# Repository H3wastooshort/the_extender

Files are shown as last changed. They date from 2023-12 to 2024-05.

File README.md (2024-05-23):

# The Extender
Modern phones suck in theor own unique way, don't they?
Hard-to-replace or -expand lithium cells, no expandable storage, and worst of all: no headphone jack!

This projects aims to fix some of those flaws by
combining a powerbank, USB hub, USB audio, and RP2040 IC into one very cursed PCB.

top pcb view
bottom pcb view
rotating pcb GIF
schematic

## Working Principle
5V power and battery charging is handled by an IP5310 powerbank IC.

The PCB connects to a phone via a low-profile 90° USB Type C cable (either [DIY](/cable) or [bought](https://de.aliexpress.com/item/1005005371248824.html)).
Once connected, the RP2040 turns on 5V power, then uses the FUSB302 to tell the phone via USB Power Delivery,
that it should keep charging while also switching into USB Data Host mode.

The phone then connects to the CH334F USB Hub IC, which in turn connects to several things:
 * a USB 3.0 socket for a USB Stick which is used to expand the internal storage,
 * the HS-100B USB audio IC, (only powered on when headphones are connected)
 * the RP2040 for HID volume and playback control aswell as FW Updates,
 * and an external USB 2.0 socket for whatever you desire.

a diagram showing data flow in the extender

## 3D-printable case
WIP

## schematic POIs

### HS-100B Audio IC
 * The Audio IC circuit is based on a low-resolution image of a reference design i found online.
 * 5V Power to the IC gets cut va a MOSFET when the headphones are disconnected. An RC circuit prevents loose plugs from causing issues. (Turns off about 1 second after unplugging)
 * The datasheet is quite sparse
 * The EEPROM data lines are connected to the RP2040, so that it can emulate the EEPROM in the future. This is not requred.

### IP5310 power-bank IC
 * I2C variant is unobtainium
 * MOSFET between VOUT and rest of system, so that power to phone and other components can be controlled
   even though VOUT can't.
 * if needed, a solder jumper can be cut and shottky diode put in place to prevent current flowing back into the IC
 * KEY pin connected to RP2040. might be needed, i don't know, should turn on when detecting a load
 * D+ and D- not connected because there is very little space. the CC lines should suffice

### CH334F
 * clock line can be grounded to use internal OSC, but this is discouraged in its datasheet.
   RP2040 is to provide a better clock once programmed.
 * 

### RP2040
 * main purpose is to communicate via USB C PD
 * might supply clock for hub
 * might be used to emulate EEPROMs for USB Hub and Audio

## more info

The [idea](/idea) directory has some partially outdated notes.

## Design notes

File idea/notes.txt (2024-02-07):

IP5XXX I2C Driver: https://git.kernel.org/pub/scm/linux/kernel/git/torvalds/linux.git/plain/drivers/power/supply/ip5xxx_power.c
IP5306 Library: https://github.com/bheesma-10/IP5306_I2C
USB C PD Stuff: https://github.com/CRImier/AltmodeFriend/tree/main ; https://github.com/CRImier/MyKiCad/tree/master/Peripherals/altmode_friend
Simple FUSB302 Lib: https://github.com/stacksmashing/tamarin-c/blob/main/FUSB302.h

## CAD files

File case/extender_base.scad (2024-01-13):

/*battery=[60,55,25];

wall_thickness=3;

module __Customizer_Limit__ () {}*/

board=[52,52,7];

translate([0,0,-(board.z+battery.z)]) union() {
difference() {
union() {
	translate([-board.x/2 -wall_thickness/2, 0,0]) cube([board.x+wall_thickness*2,board.y+wall_thickness*2,board.z+wall_thickness]);

	translate([-battery.x/2 -wall_thickness/2, 0,board.z]) 
		difference() {
			cube([battery.x+wall_thickness*2,battery.y+wall_thickness*2,battery.z+wall_thickness]);
			translate([wall_thickness,wall_thickness,wall_thickness+0.001]) cube(battery);
	}
}
union() {
	translate([-board.x/2, wall_thickness, wall_thickness]) cube([board.x,board.y-wall_thickness,board.z+wall_thickness*2]);
	translate([-board.x/2, 0, wall_thickness]) cube([board.x,wall_thickness, board.z]);
}
}


//connector fill here 
}

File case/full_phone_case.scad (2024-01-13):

phone=[80,165,10];

phone_corner_radius=15;

//distance from bottom to naerest of naerest button on the right
button_cutout_right_start=12;
//distance from bottom to farthest edge of farthest button on the right
button_cutout_right_stop=15;
//distance from bottom to farthest edge of farthest button on the left
button_cutout_left_start=0;
//distance from bottom to farthest edge of farthest button on the left
button_cutout_left_stop=0;

battery=[60,55,25];

wall_thickness=3;

module __Customizer_Limit__ () {}

include <extender_base.scad>


//phe case stoff here

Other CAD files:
case/stitch_on_case.scad

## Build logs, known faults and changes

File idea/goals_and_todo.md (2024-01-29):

#### Legend
[F] Failed / not implementing
[ ] Not yet finished
[-] In Progress
[X] Done

## Goals:
### Main
[-] USB PD Power SRC and Data Device (not Host)
[X] Expand Storage
[X] Connect Headphones
	[X] Only enable headphones if present
	[X] Only enable microphone if present
[X] Charge via USB C
[-] Low Profile USB C Cable
### Additional
[F] Charge other devices via USB C
[X] Have extra USB data socket
[-] Volume Controls on headphone Cable
	[X] HW
	[ ] SW

## TODO
### Main
 * CHECK SWREG DESIGN! (Inductor values, layout, ...)
 * COMPARE DIY FOOTPRINTS WITH LCSC VERSIONS!
 * reconsider DIY cable design. make version w/o USB3
 * battery protection PCB?
 * make combined stencil

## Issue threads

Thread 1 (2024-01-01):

Altmode Friend board

CRImier, 2024-01-01:
Figure out a way to get me [your address[(https://gist.github.com/CRImier/2b8e9f327e148f9c27f29578b8ef220a), I can mail you an Altmode Friend devboard!

H3wastooshort, 2024-01-01:
Thank you very much!

You can message me on Matrix at [@h3:tchncs.de](https://matrix.to/#/@h3:tchncs.de) if that's is alright for you.

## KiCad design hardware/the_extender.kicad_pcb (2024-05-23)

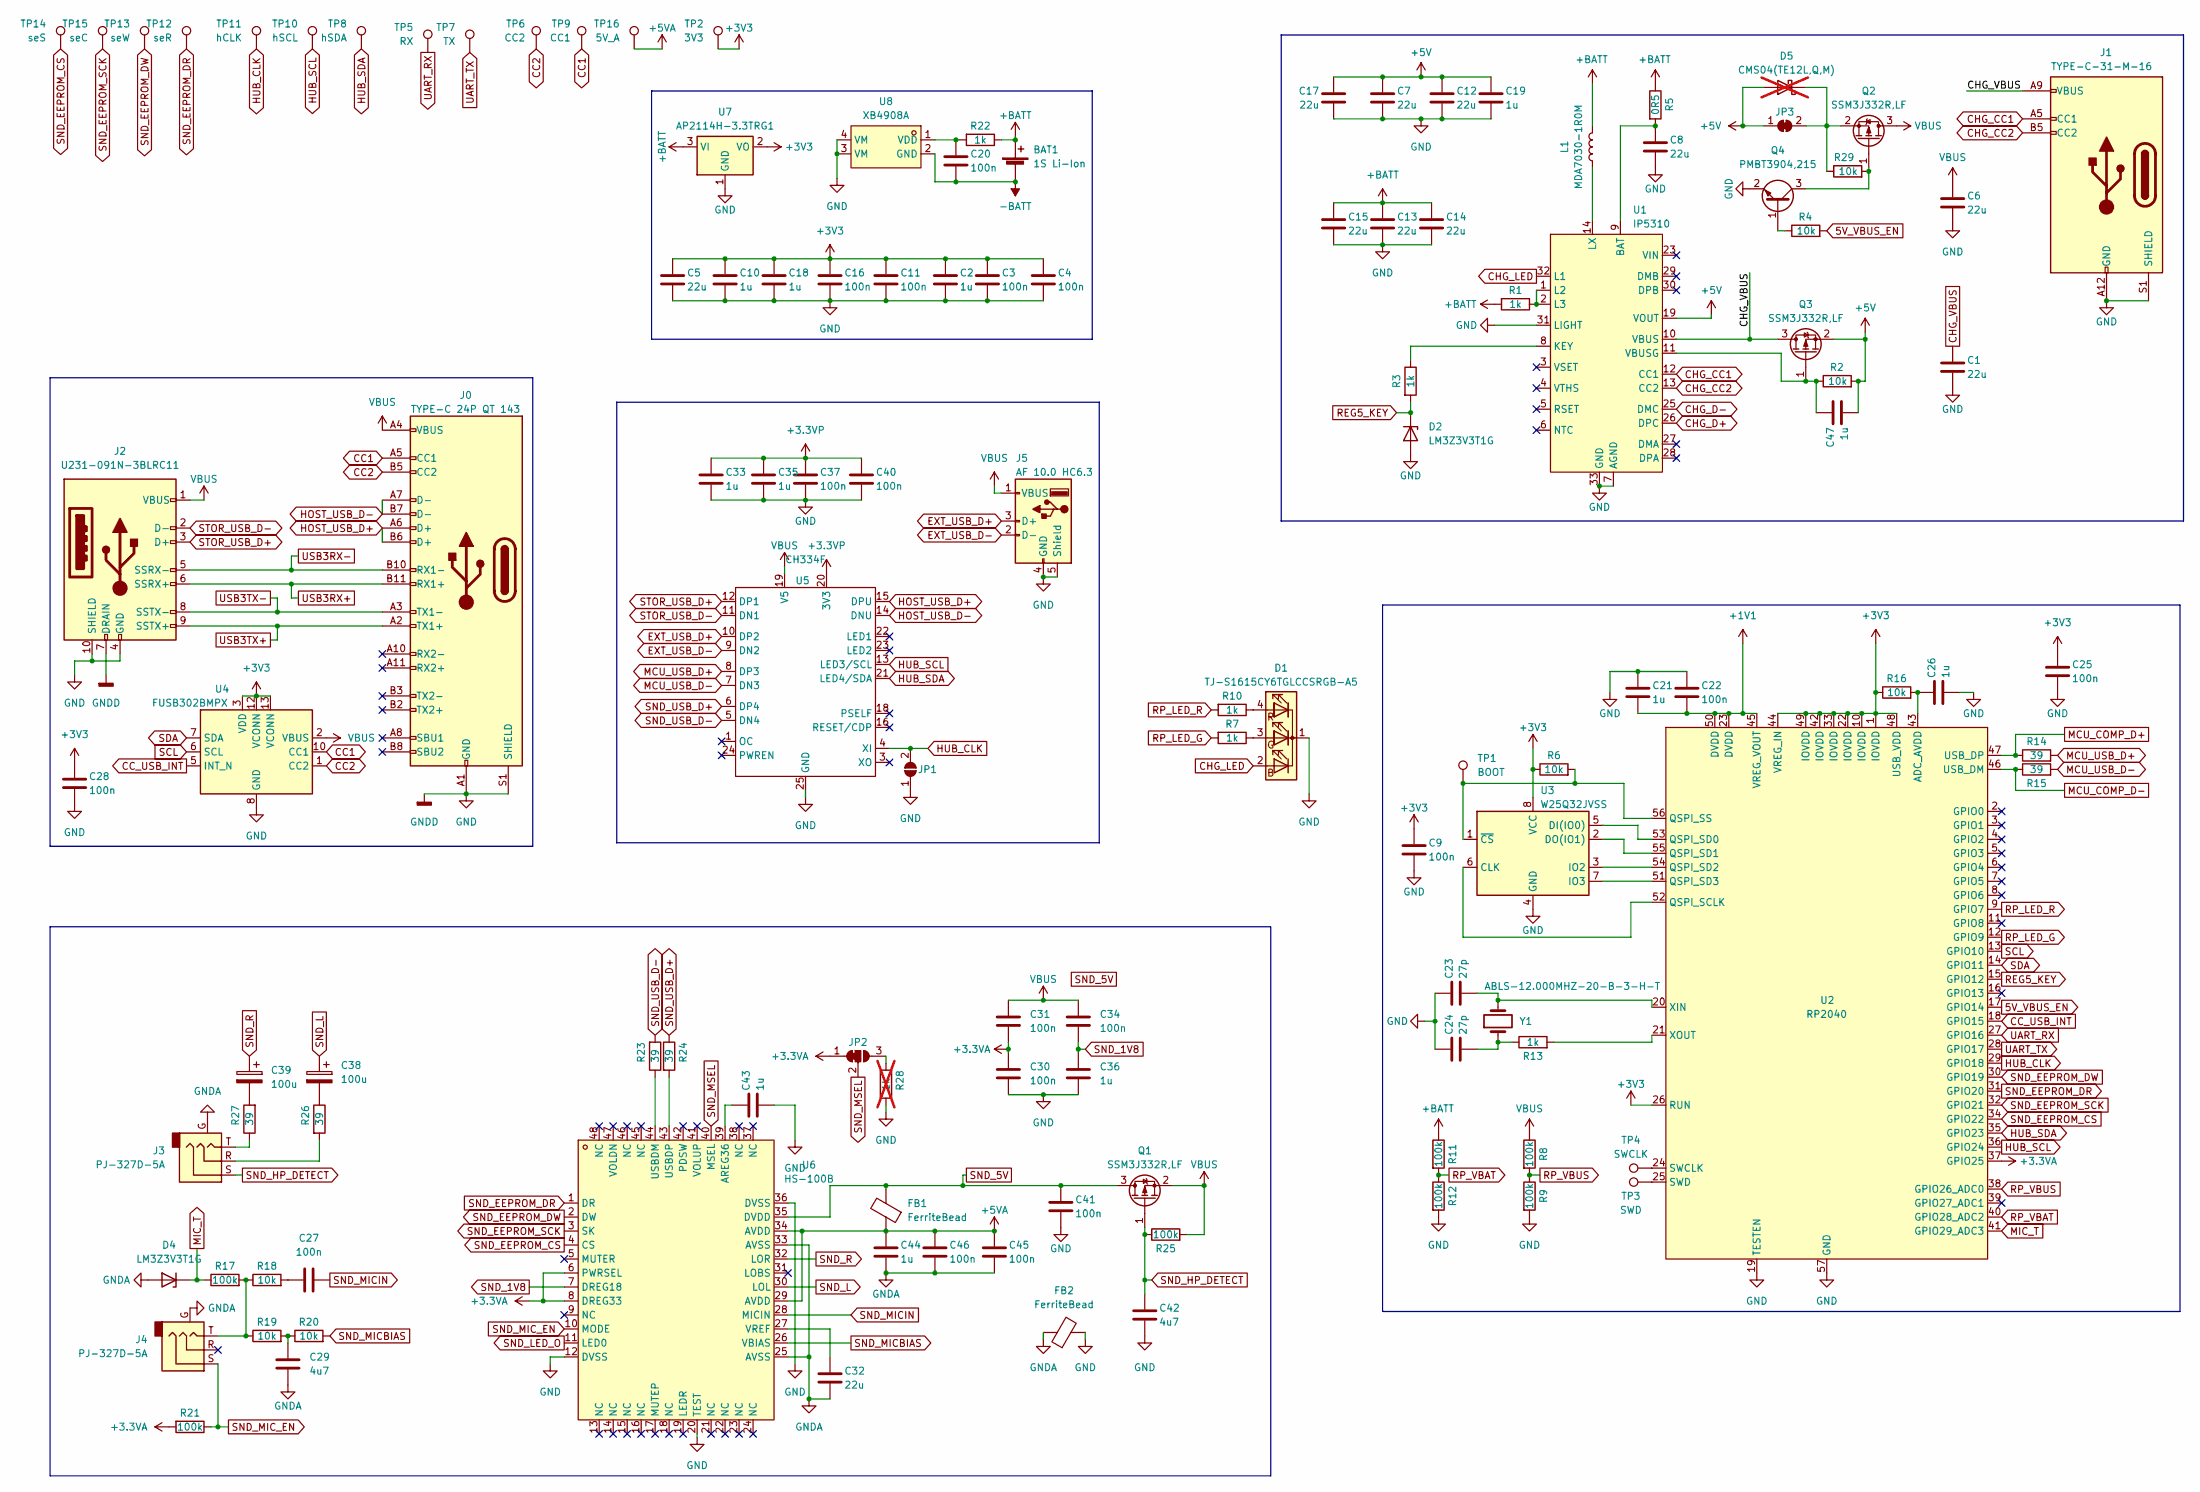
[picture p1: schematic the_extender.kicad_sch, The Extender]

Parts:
BAT1: 1S Li-Ion; PinHeader_1x02_P2.54mm_Vertical
C1, C5, C6, C7, C8, C12, C13, C14, C15, C17, C32: 22u; C_1206_3216Metric_Pad1.33x1.80mm_HandSolder; LCSC C12891
C2, C10, C18, C19, C21, C26, C33, C35, C36, C43, C44, C47: 1u; C_0805_2012Metric_Pad1.18x1.45mm_HandSolder; LCSC C116352
C3, C4, C9, C11, C16, C20, C22, C25, C27, C28, C30, C31, C34, C37, C40, C41, C45, C46: 100n; C_0805_2012Metric_Pad1.18x1.45mm_HandSolder; LCSC C1711
C23, C24: 27p; C_0805_2012Metric_Pad1.18x1.45mm_HandSolder; LCSC C525289
C29, C42: 4u7; C_0805_2012Metric_Pad1.18x1.45mm_HandSolder; LCSC C1779
C38, C39: 100u; C_1206_3216Metric_Pad1.33x1.80mm_HandSolder; LCSC C15008
D1: TJ-S1615CY6TGLCCSRGB-A5; LED-ARRAY-SMD_4P-L1.6-W1.5-BL-FD; LCSC C601684
D2, D4: LM3Z3V3T1G; D_SOD-323_HandSoldering; LCSC C46279
D5: CMS04(TE12L,Q,M); D_SOD-128; LCSC C603062; not fitted
FB1, FB2: FerriteBead; L_0805_2012Metric_Pad1.05x1.20mm_HandSolder; LCSC C394433
J0: TYPE-C 24P QT 143; TYPE-C-SMD_C9900025773; LCSC Part C5156605
J1: TYPE-C-31-M-16; LCSC C283541
J2: U231-091N-3BLRC11; USB-A-TH_XKB_U231-091N-XXX; LCSC Part C2880594
J3, J4: PJ-327D-5A; AUDIO-TH_PJ-327D-5A; LCSC Part C707229
J5: AF 10.0 HC6.3; USB-A-TH_AF-10.0-HC6.3; LCSC Part C456017
JP1: SolderJumper_2_Open; SolderJumper-2_P1.3mm_Open_TrianglePad1.0x1.5mm
JP2: SolderJumper_3_Bridged12; SolderJumper-3_P1.3mm_Bridged12_Pad1.0x1.5mm_NumberLabels
JP3: SolderJumper_2_Bridged; SolderJumper-2_P1.3mm_Bridged_Pad1.0x1.5mm
L1: MDA7030-1R0M; IND-SMD_L7.1-W6.6; LCSC Part C2847480
Q1, Q2, Q3: SSM3J332R,LF; SOT-23_Handsoldering; LCSC C146367
Q4: PMBT3904,215; SOT-23_Handsoldering; LCSC C8667
R1, R3, R7, R10, R13, R22: 1k; R_0805_2012Metric_Pad1.20x1.40mm_HandSolder; LCSC C110774
R2, R4, R6, R16, R18, R19, R20, R29: 10k; R_0805_2012Metric_Pad1.20x1.40mm_HandSolder; LCSC C217770
R5: 0R5; R_0805_2012Metric_Pad1.20x1.40mm_HandSolder; LCSC C218422
R8, R9, R11, R12, R17, R21, R25: 100k; R_0805_2012Metric_Pad1.20x1.40mm_HandSolder; LCSC C217765
R14, R15, R23, R24, R26, R27: 39; R_0805_2012Metric_Pad1.20x1.40mm_HandSolder; LCSC C2828722
R28: 1k; R_0805_2012Metric_Pad1.20x1.40mm_HandSolder; LCSC C110774; not fitted
TP1: BOOT; TestPoint_Pad_D2.0mm
TP2: 3V3; TestPoint_Pad_D2.0mm
TP3: SWD; TestPoint_Pad_D2.0mm
TP4: SWCLK; TestPoint_Pad_D2.0mm
TP5: RX; TestPoint_Pad_D1.0mm
TP6: CC2; TestPoint_Pad_D1.0mm
TP7: TX; TestPoint_Pad_D2.0mm
TP8: hSDA; TestPoint_Pad_D1.0mm
TP9: CC1; TestPoint_Pad_D1.0mm
TP10: hSCL; TestPoint_Pad_D1.0mm
TP11: hCLK; TestPoint_Pad_D1.0mm
TP12: seR; TestPoint_Pad_D2.0mm
TP13: seW; TestPoint_Pad_D2.0mm
TP14: seS; TestPoint_Pad_D2.0mm
TP15: seC; TestPoint_Pad_D2.0mm
TP16: 5V_A; TestPoint_Pad_D2.0mm
U1: IP5310; QFN-32_L5.0-W5.0-P0.50-BL-EP3.4; LCSC Part C191176
U2: RP2040; LQFN-56_L7.0-W7.0-P0.4-EP; LCSC Part C2040
U3: W25Q32JVSS; SOIC-8_5.23x5.23mm_P1.27mm; LCSC C179173
U4: FUSB302BMPX; WQFN-14-1EP_2.5x2.5mm_P0.5mm_EP1.45x1.45mm; LCSC Part C442699
U5: CH334F; QFN-24-1EP_4x4mm_P0.5mm_EP2.6x2.6mm; LCSC Part C5187527
U6: HS-100B; LQFP-48_7x7mm_P0.5mm; LCSC Part C371351
U7: AP2114H-3.3TRG1; SOT-223-3_TabPin2; LCSC C150716
U8: XB4908A; ESN-4_L2.8-W2.3-LS3.7-BL; LCSC Part C2998740
Y1: ABLS-12.000MHZ-20-B-3-H-T; Crystal_SMD_7050-2Pin_7.0x5.0mm_HandSoldering; LCSC C1985323

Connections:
5V_VBUS_EN: R4.2, U2.17 (GPIO14)
+1V1: C21.2, C22.2, U2.23 (DVDD), U2.45 (VREG_VOUT), U2.50 (DVDD)
+3.3VA: C30.2, C31.1, JP2.1 (A), R21.2, U2.37 (GPIO25), U6.6 (PWRSEL), U6.8 (DREG33)
+3.3VP: C33.1, C35.1, C37.1, C40.1, U5.20 (3V3)
+3V3: C2.1, C3.1, C4.1, C5.1, C9.1, C10.1, C11.1, C16.1, C18.1, C25.1, C28.1, R6.1, R16.1, TP2.1, U2.1 (IOVDD), U2.10 (IOVDD), U2.22 (IOVDD), U2.26 (RUN), U2.33 (IOVDD), U2.42 (IOVDD), U2.44 (VREG_IN), U2.48 (USB_VDD), U2.49 (IOVDD), U3.8 (VCC), U4.3 (VDD), U4.4 (VDD), U4.12 (VCONN), U4.13 (VCONN), U7.2 (VO)
+5V: C7.1, C12.1, C17.1, C19.1, C47.2, D5.2 (A), JP3.1 (A), Q3.2 (S), R2.2, U1.19 (VOUT), U1.20 (VOUT), U1.21 (VOUT), U1.22 (VOUT)
+5VA: C44.1, C45.1, C46.1, FB1.1, TP16.1, U6.29 (AVDD), U6.34 (AVDD)
+BATT: BAT1.1 (+), C13.1, C14.1, C15.1, L1.2, R1.2, R5.1, R11.1, R22.1, U7.3 (VI)
-BATT: BAT1.2 (-), C20.2, U8.2 (GND)
CC1: J0.A5 (CC1), TP9.1, U4.10 (CC1), U4.11 (CC1)
CC2: J0.B5 (CC2), TP6.1, U4.1 (CC2), U4.14 (CC2)
CC_USB_INT: U2.18 (GPIO15), U4.5 (INT_N)
CHG_CC1: J1.A5 (CC1), U1.12 (CC1)
CHG_CC2: J1.B5 (CC2), U1.13 (CC2)
CHG_D+: U1.26 (DPC)
CHG_D-: U1.25 (DMC)
CHG_LED: D1.2 (BA), U1.32 (L1)
CHG_VBUS: C1.1, J1.A9 (VBUS), J1.B9 (VBUS), Q3.3 (D), U1.10 (VBUS)
EXT_USB_D+: J5.3 (D+), U5.10 (DP2)
EXT_USB_D-: J5.2 (D-), U5.9 (DN2)
GND: C1.2, C2.2, C3.2, C4.2, C5.2, C6.2, C7.2, C8.2, C9.2, C10.2, C11.2, C12.2, C13.2, C14.2, C15.2, C16.2, C17.2, C18.2, C19.2, C21.1, C22.1, C23.1, C24.1, C25.2, C26.2, C28.2, C30.1, C33.2, C35.2, C36.1, C37.2, C40.2, C41.2, C42.2, C43.2, D1.1 (K), D2.2 (A), FB2.2, J0.A1 (GND), J0.A12 (GND), J0.B1 (GND), J0.B12 (GND), J0.S1 (SHIELD), J1.A12 (GND), J1.B12 (GND), J1.S1 (SHIELD), J2.4 (GND), J2.7 (DRAIN), J2.10 (SHIELD), J5.4 (GND), J5.5 (Shield), JP1.1 (A), Q4.2 (E), R9.2, R12.2, R28.1, U1.7 (AGND), U1.31 (LIGHT), U1.33 (GND), U2.19 (TESTEN), U2.57 (GND), U3.4 (GND), U4.8 (GND), U4.9 (GND), U4.15 (GND), U5.25 (GND), U6.12 (DVSS), U6.20 (TEST), U6.36 (DVSS), U7.1 (GND), U8.3 (VM), U8.4 (VM)
GNDA: C29.1, C32.2, C44.2, C45.2, C46.2, D4.2 (A), FB2.1, J3.G, J4.G, U6.25 (AVSS), U6.33 (AVSS)
HOST_USB_D+: J0.A6 (D+), J0.B6 (D+), U5.15 (DPU)
HOST_USB_D-: J0.A7 (D-), J0.B7 (D-), U5.14 (DNU)
HUB_CLK: JP1.2 (B), TP11.1, U2.29 (GPIO18), U5.4 (XI)
HUB_SCL: TP10.1, U2.36 (GPIO24), U5.13 (LED3/SCL)
HUB_SDA: TP8.1, U2.35 (GPIO23), U5.21 (LED4/SDA)
MCU_COMP_D+: R14.1, U2.47 (USB_DP)
MCU_COMP_D-: R15.1, U2.46 (USB_DM)
MCU_USB_D+: R14.2, U5.8 (DP3)
MCU_USB_D-: R15.2, U5.7 (DN3)
MIC_T: D4.1 (K), R17.1, U2.41 (GPIO29_ADC3)
unnamed: C24.2, R13.1, Y1.1
unnamed: C27.1, R18.2
unnamed: C29.2, R19.2, R20.1
unnamed: C38.2, R26.1
unnamed: C39.2, R27.2
unnamed: D1.3 (GA), R7.1
unnamed: D1.4 (RA), R10.1
unnamed: D5.1 (K), JP3.2 (B), Q2.2 (S), R29.1
unnamed: J3.R, R26.2
unnamed: J3.T, R27.1
unnamed: J4.T, R17.2, R18.1, R19.1
unnamed: JP2.3 (B), R28.2
unnamed: L1.1, U1.14 (LX), U1.15 (LX), U1.16 (LX), U1.17 (LX), U1.18 (LX)
unnamed: Q2.1 (G), Q4.3 (C), R29.2
unnamed: C47.1, Q3.1 (G), R2.1, U1.11 (VBUSG)
unnamed: Q4.1 (B), R4.1
unnamed: C8.1, R5.2, U1.9 (BAT)
unnamed: R3.1, U1.8 (KEY)
unnamed: R1.1, U1.1 (L2), U1.2 (L3)
unnamed: C26.1, R16.2, U2.43 (ADC_AVDD)
unnamed: U2.52 (QSPI_SCLK), U3.6 (CLK)
unnamed: U2.53 (QSPI_SD0), U3.5 (DI(IO0))
unnamed: U2.55 (QSPI_SD1), U3.2 (DO(IO1))
unnamed: U2.54 (QSPI_SD2), U3.3 (IO2)
unnamed: U2.51 (QSPI_SD3), U3.7 (IO3)
unnamed: R6.2, TP1.1, U2.56 (QSPI_SS), U3.1 (~CS)
unnamed: TP4.1, U2.24 (SWCLK)
unnamed: TP3.1, U2.25 (SWD)
unnamed: C23.2, U2.20 (XIN), Y1.2
unnamed: R13.2, U2.21 (XOUT)
unnamed: C43.1, U6.39 (AREG36)
unnamed: R23.1, U6.44 (USBDM)
unnamed: R24.2, U6.43 (USBDP)
unnamed: C32.1, U6.27 (VREF)
unnamed: C20.1, R22.2, U8.1 (VDD)
REG5_KEY: D2.1 (K), R3.2, U2.15 (GPIO12)
RP_LED_G: R7.2, U2.12 (GPIO9)
RP_LED_R: R10.2, U2.9 (GPIO7)
RP_VBAT: R11.2, R12.1, U2.40 (GPIO28_ADC2)
RP_VBUS: R8.2, R9.1, U2.38 (GPIO26_ADC0)
SCL: U2.13 (GPIO10), U4.6 (SCL)
SDA: U2.14 (GPIO11), U4.7 (SDA)
SND_1V8: C34.1, C36.2, U6.7 (DREG18)
SND_5V: C41.1, FB1.2, Q1.3 (D), U6.35 (DVDD)
SND_EEPROM_CS: TP14.1, U2.34 (GPIO22), U6.4 (CS)
SND_EEPROM_DR: TP12.1, U2.31 (GPIO20), U6.1 (DR)
SND_EEPROM_DW: TP13.1, U2.30 (GPIO19), U6.2 (DW)
SND_EEPROM_SCK: TP15.1, U2.32 (GPIO21), U6.3 (SK)
SND_HP_DETECT: C42.1, J3.S, Q1.1 (G), R25.1
SND_L: C38.1, U6.30 (LOL)
SND_LED_O: U6.11 (LED0)
SND_MICBIAS: R20.2, U6.26 (VBIAS)
SND_MICIN: C27.2, U6.28 (MICIN)
SND_MIC_EN: J4.S, R21.1, U6.10 (MODE)
SND_MSEL: JP2.2 (C), U6.40 (MSEL)
SND_R: C39.1, U6.32 (LOR)
SND_USB_D+: R24.1, U5.6 (DP4)
SND_USB_D-: R23.2, U5.5 (DN4)
STOR_USB_D+: J2.3 (D+), U5.12 (DP1)
STOR_USB_D-: J2.2 (D-), U5.11 (DN1)
UART_RX: TP5.1, U2.27 (GPIO16)
UART_TX: TP7.1, U2.28 (GPIO17)
USB3RX+: J0.B11 (RX1+), J2.6 (SSRX+)
USB3RX-: J0.B10 (RX1-), J2.5 (SSRX-)
USB3TX+: J0.A2 (TX1+), J2.9 (SSTX+)
USB3TX-: J0.A3 (TX1-), J2.8 (SSTX-)
VBUS: C6.1, C31.2, C34.2, J0.A4 (VBUS), J0.A9 (VBUS), J0.B4 (VBUS), J0.B9 (VBUS), J2.1 (VBUS), J5.1 (VBUS), Q1.2 (S), Q2.3 (D), R8.1, R25.2, U4.2 (VBUS), U5.19 (V5)

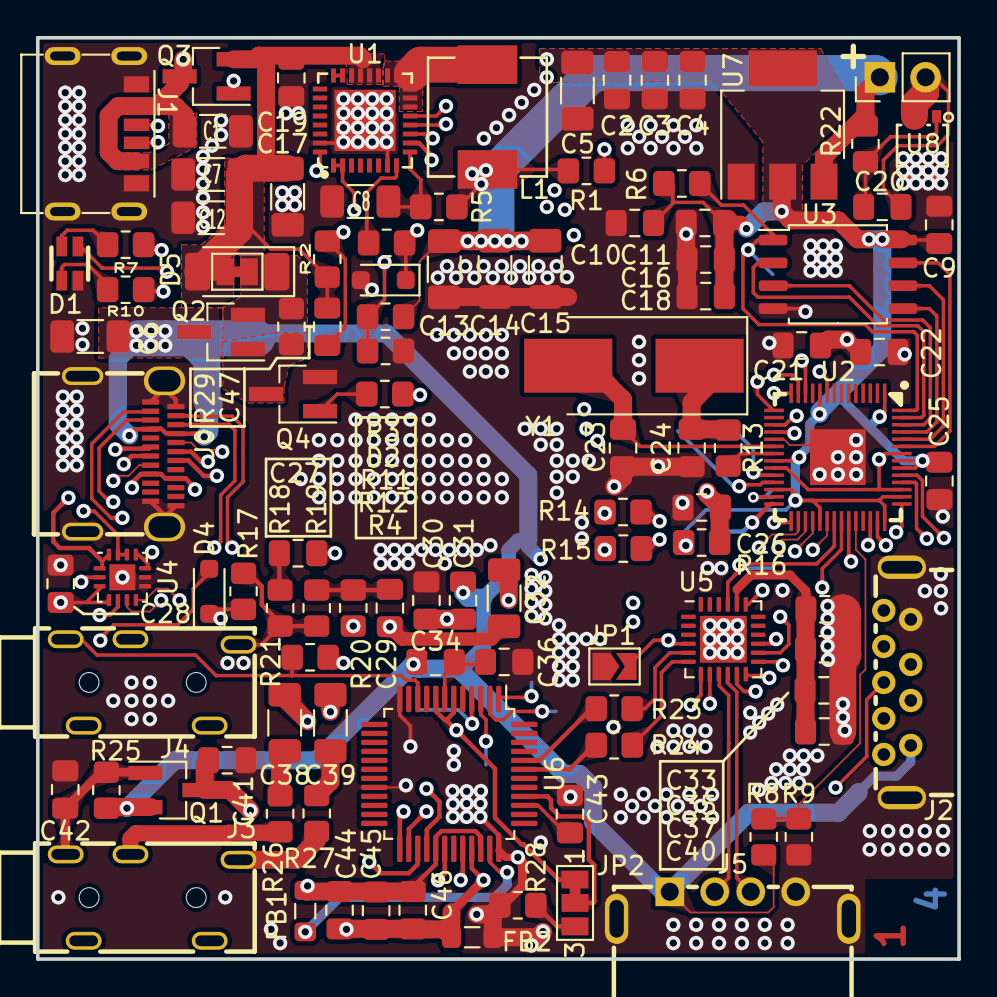
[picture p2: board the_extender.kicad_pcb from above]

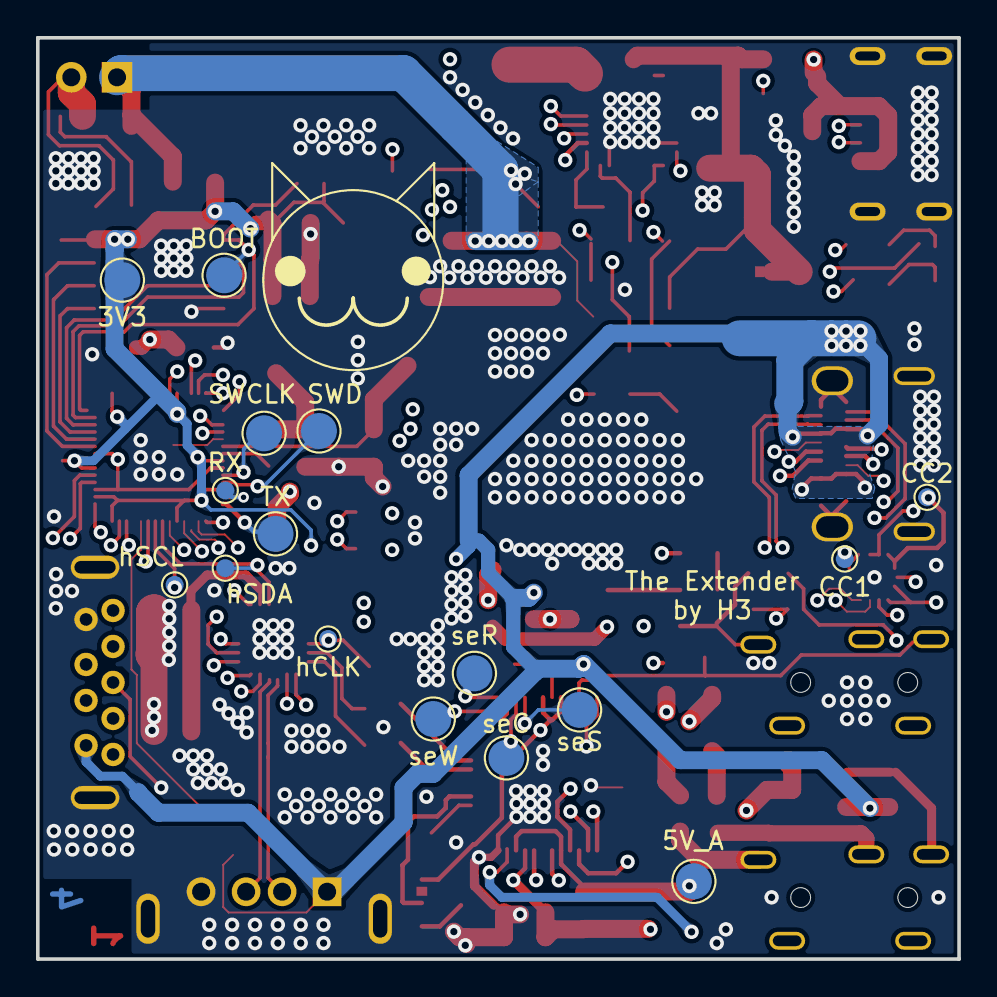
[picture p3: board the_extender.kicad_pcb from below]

Board: 4 copper layers, 51.2 x 51.2 mm, 122 parts (16 on the bottom side), 96 nets.

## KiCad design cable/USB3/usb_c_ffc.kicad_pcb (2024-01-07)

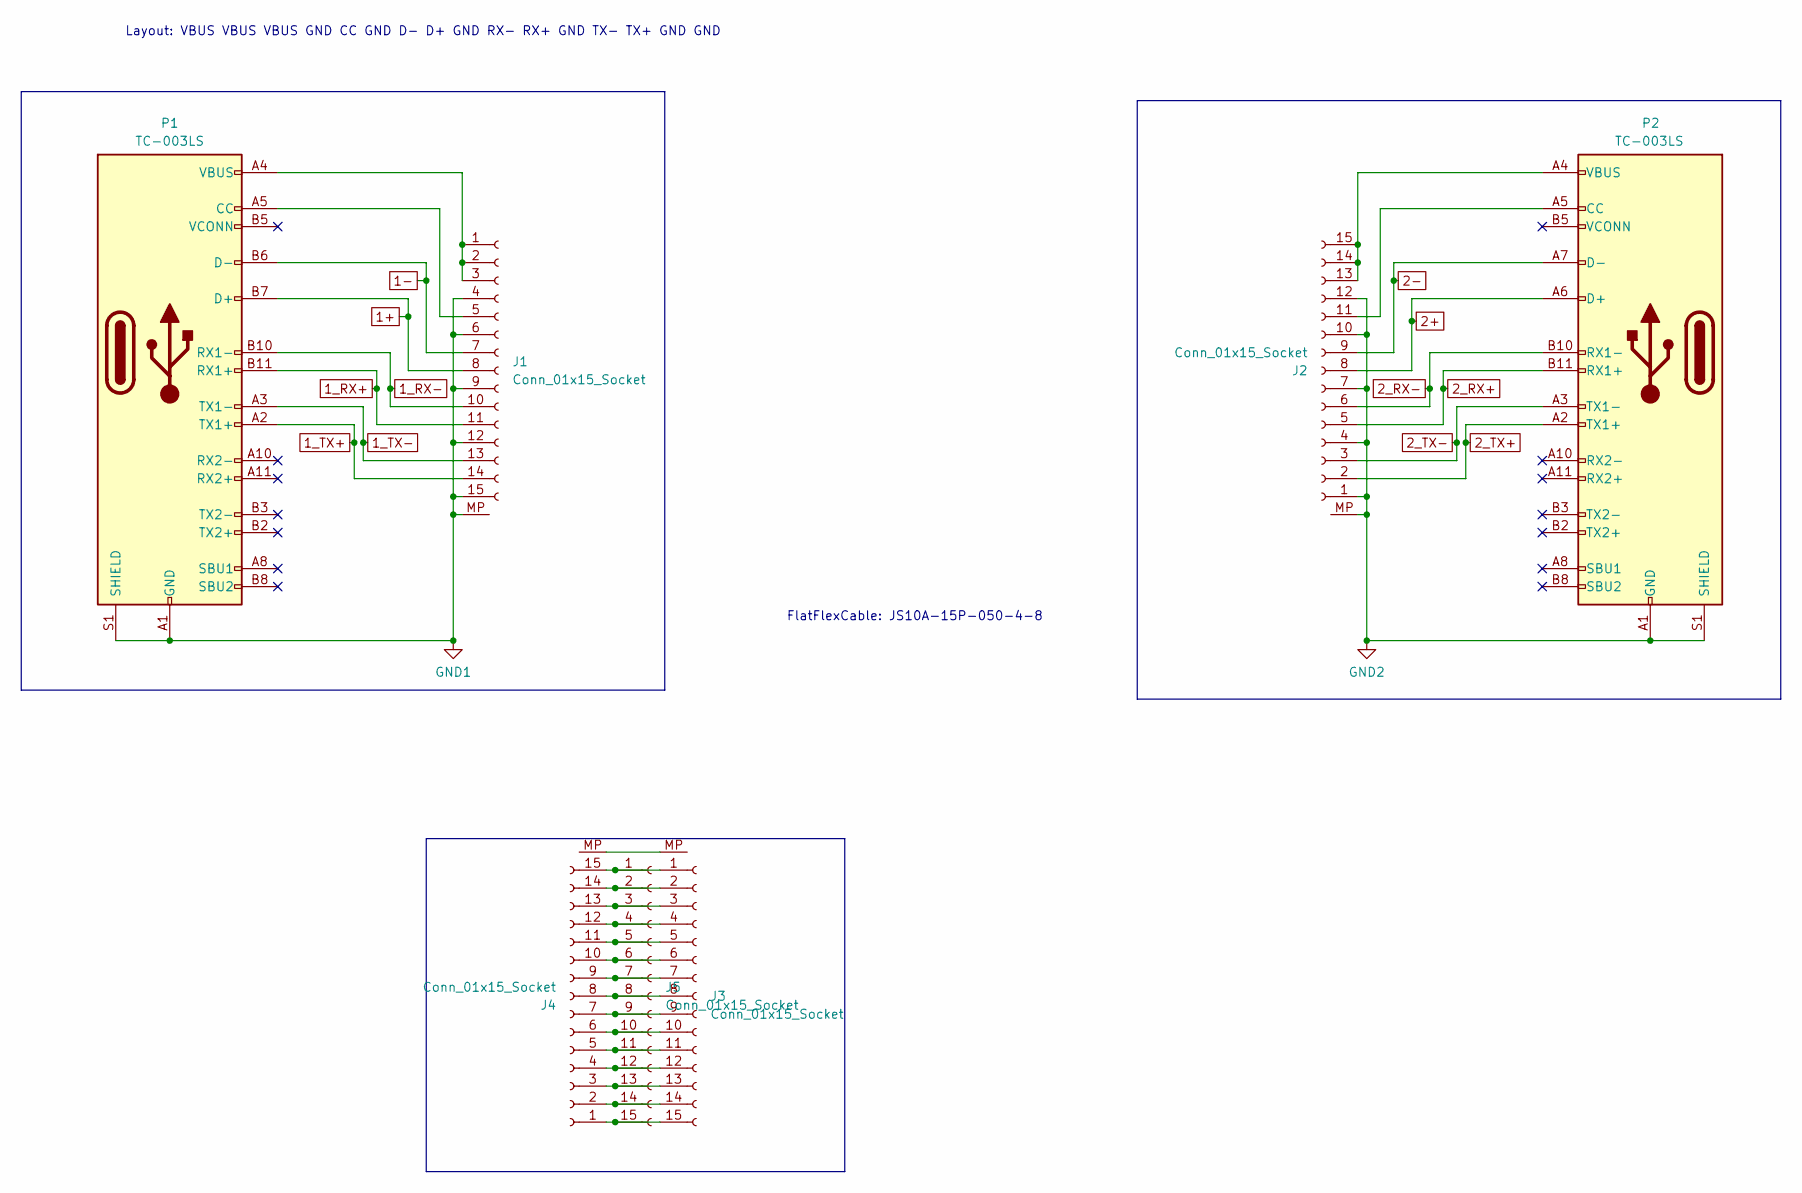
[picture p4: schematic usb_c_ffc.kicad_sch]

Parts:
J1, J2, J3, J4: Conn_01x15_Socket; Molex_200528-0150_1x15-1MP_P1.00mm_Horizontal
J5: Conn_01x15_Socket; PinHeader_1x15_P2.54mm_Vertical
P1, P2: TC-003LS

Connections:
1+: J1.8, P1.B7 (D+)
1-: J1.7, P1.B6 (D-)
1_RX+: J1.11, P1.B11 (RX1+)
1_RX-: J1.10, P1.B10 (RX1-)
1_TX+: J1.14, P1.A2 (TX1+)
1_TX-: J1.13, P1.A3 (TX1-)
2+: J2.8, P2.A6 (D+)
2-: J2.9, P2.A7 (D-)
2_RX+: J2.5, P2.B11 (RX1+)
2_RX-: J2.6, P2.B10 (RX1-)
2_TX+: J2.2, P2.A2 (TX1+)
2_TX-: J2.3, P2.A3 (TX1-)
GND1: J1.4, J1.6, J1.9, J1.12, J1.15, J1.MP, P1.A1 (GND), P1.A12 (GND), P1.B1 (GND), P1.B12 (GND), P1.S1 (SHIELD)
GND2: J2.1, J2.4, J2.7, J2.10, J2.12, J2.MP, P2.A1 (GND), P2.A12 (GND), P2.B1 (GND), P2.B12 (GND), P2.S1 (SHIELD)
unnamed: J1.1, J1.2, J1.3, P1.A4 (VBUS), P1.A9 (VBUS), P1.B4 (VBUS), P1.B9 (VBUS)
unnamed: J1.5, P1.A5 (CC)
unnamed: J2.11, P2.A5 (CC)
unnamed: J2.13, J2.14, J2.15, P2.A4 (VBUS), P2.A9 (VBUS), P2.B4 (VBUS), P2.B9 (VBUS)
unnamed: J3.MP, J4.MP
unnamed: J3.1, J4.15, J5.1
unnamed: J3.2, J4.14, J5.2
unnamed: J3.3, J4.13, J5.3
unnamed: J3.4, J4.12, J5.4
unnamed: J3.5, J4.11, J5.5
unnamed: J3.6, J4.10, J5.6
unnamed: J3.7, J4.9, J5.7
unnamed: J3.8, J4.8, J5.8
unnamed: J3.9, J4.7, J5.9
unnamed: J3.10, J4.6, J5.10
unnamed: J3.11, J4.5, J5.11
unnamed: J3.12, J4.4, J5.12
unnamed: J3.13, J4.3, J5.13
unnamed: J3.14, J4.2, J5.14
unnamed: J3.15, J4.1, J5.15

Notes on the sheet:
FlatFlexCable: JS10A-15P-050-4-8
Layout: VBUS VBUS VBUS GND CC GND D- D+ GND RX- RX+ GND TX- TX+ GND GND

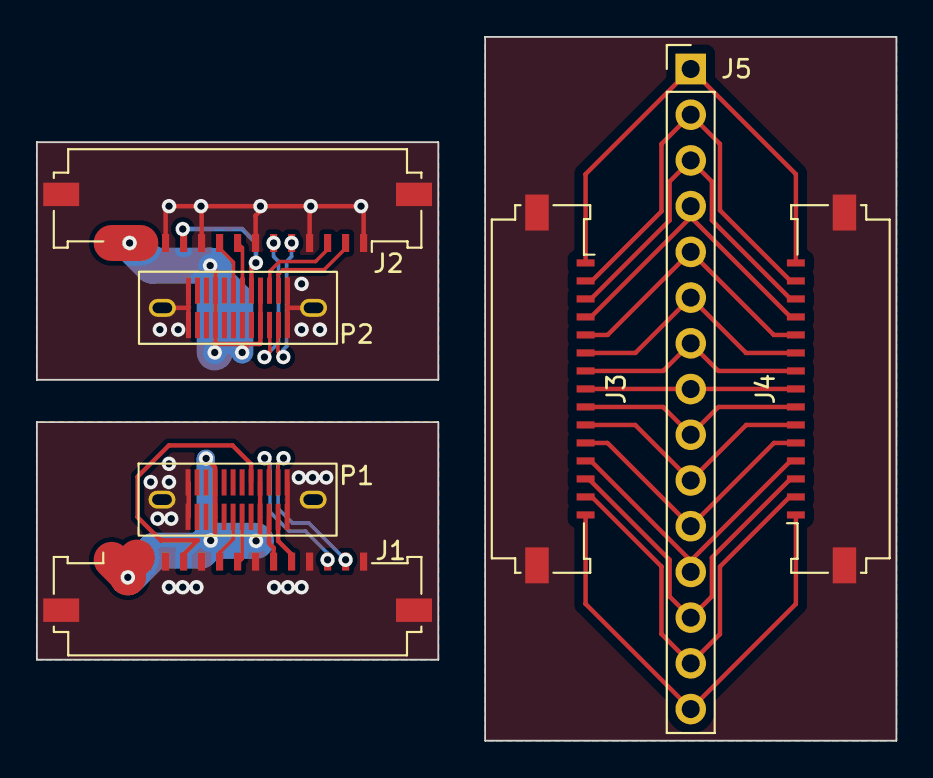
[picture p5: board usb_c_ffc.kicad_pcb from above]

Board: 2 copper layers, 47.8 x 39.1 mm, 7 parts (0 on the bottom side), 34 nets.

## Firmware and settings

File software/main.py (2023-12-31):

####
####
# This Code is licensed under the GNU General Public License 3
# https://www.gnu.org/licenses/gpl-3.0.html
# Original Author: @CRImier on GitHub
# Original Code: https://github.com/CRImier/AltmodeFriend/blob/main/main.py
# Modified by H3
####
####


from machine import Pin, I2C, ADC, freq
from time import sleep, ticks_us, ticks_diff
import sys

i2c = I2C(sda=Pin(11), scl=Pin(10), id=1, freq=100000)
i2c_hub = I2C(sda=Pin(23), scl=Pin(24), id=2, freq=100000)
print(i2c.scan(), start="Sys I2C:\n")
print(i2c_hub.scan(), start="Hub I2C:\n")


########################
#
# IP5310 stuff
#
########################

def ip5310_defaults()
    pass # set everything the enable/disble functions dont touch

def enable_5V():
    ip5310_defaults()
    pass # toggle KEY, then enable 5V boost and disable auto-shutdown

def disable_5V():
    ip5310_defaults()
    pass # disable auto-power-up of boost converter, then disable boost converter

def set_power_rail(rail):
    if rail == '5V':
        enable_5V()
    else:
        disable_5V()
    pass

########################
#
# USB stuff
#
########################

def enter_low_power_mode():
    freq(3000)
    pass #opposite of normal mode

def enter_normal_mode():
    freq(12000)
    pass # enable 24M Clock Output, enable 3V3 for USB Hub, start hub I2C

########################
#
# FUSB-specific code
#
########################

FUSB302_I2C_SLAVE_ADDR = 0x22
TCPC_REG_DEVICE_ID = 0x01
TCPC_REG_SWITCHES0 = 0x02
TCPC_REG_SWITCHES1 = 0x03
TCPC_REG_MEASURE = 0x04
TCPC_REG_CONTROL0 = 0x06
TCPC_REG_CONTROL1 = 0x07
TCPC_REG_CONTROL2 = 0x08
TCPC_REG_CONTROL3 = 0x09
TCPC_REG_MASK = 0x0A
TCPC_REG_POWER = 0x0B
TCPC_REG_RESET = 0x0C
TCPC_REG_MASKA = 0x0E
TCPC_REG_MASKB = 0x0F
TCPC_REG_STATUS0A = 0x3C
TCPC_REG_STATUS1A = 0x3D
TCPC_REG_INTERRUPTA = 0x3E
TCPC_REG_INTERRUPTB = 0x3F
TCPC_REG_STATUS0 = 0x40
TCPC_REG_STATUS1 = 0x41
TCPC_REG_INTERRUPT = 0x42
TCPC_REG_FIFOS = 0x43

def reset():
    # reset the entire FUSB
    i2c.writeto_mem(FUSB302_I2C_SLAVE_ADDR, TCPC_REG_RESET, bytes([0b1]))

def reset_pd():
    # resets the FUSB PD logic
    i2c.writeto_mem(FUSB302_I2C_SLAVE_ADDR, TCPC_REG_RESET, bytes([0b10]))

def unmask_all():
    # unmasks all interrupts
    i2c.writeto_mem(FUSB302_I2C_SLAVE_ADDR, TCPC_REG_MASK, bytes([0b0]))
    i2c.writeto_mem(FUSB302_I2C_SLAVE_ADDR, TCPC_REG_MASKA, bytes([0b0]))
    i2c.writeto_mem(FUSB302_I2C_SLAVE_ADDR, TCPC_REG_MASKB, bytes([0b0]))

def cc_current():
    # show measured CC level interpreted as USB-C current levels
    return i2c.readfrom_mem(FUSB302_I2C_SLAVE_ADDR, TCPC_REG_STATUS0, 1)[0] & 0b11

def read_cc(cc):
    # enable a CC pin for reading
    assert(cc in [0, 1, 2])
    x = i2c.readfrom_mem(FUSB302_I2C_SLAVE_ADDR, TCPC_REG_SWITCHES0, 1)[0]
    x1 = x
    clear_mask = ~0b1100 & 0xFF
    x &= clear_mask
    mask = [0b0, 0b100, 0b1000][cc]
    x |= mask
    #print('TCPC_REG_SWITCHES0: ', bin(x1), bin(x), cc)
    i2c.writeto_mem(FUSB302_I2C_SLAVE_ADDR, TCPC_REG_SWITCHES0, bytes((x,)) )

def enable_pullups():
    # enable host pullups on CC pins, disable pulldowns
    x = i2c.readfrom_mem(0x22, 0x02, 1)[0]
    x |= 0b11000000
    i2c.writeto_mem(0x22, 0x02, bytes((x,)) )

def set_mdac(value):
    x = i2c.readfrom_mem(0x22, 0x04, 1)[0]
    x &= 0b11000000
    x |= value
    i2c.writeto_mem(0x22, 0x04, bytes((x,)) )

def enable_sop():
    # enable reception of SOP'/SOP" messages
    x = i2c.readfrom_mem(FUSB302_I2C_SLAVE_ADDR, TCPC_REG_CONTROL1, 1)[0]
    mask = 0b1100011
    x |= mask
    i2c.writeto_mem(FUSB302_I2C_SLAVE_ADDR, TCPC_REG_CONTROL1, bytes((x,)) )

def disable_pulldowns():
    x = i2c.readfrom_mem(FUSB302_I2C_SLAVE_ADDR, TCPC_REG_SWITCHES0, 1)[0]
    clear_mask = ~0b11 & 0xFF
    x &= clear_mask
    i2c.writeto_mem(FUSB302_I2C_SLAVE_ADDR, TCPC_REG_SWITCHES0, bytes((x,)) )

def measure_source(debug=False):
    # read CC pins and see which one senses the correct host current
    read_cc(1)
    sleep(0.001)
    cc1_c = cc_current()
    read_cc(2)
    sleep(0.001)
    cc2_c = cc_current()
    if cc1_c == host_current:
        cc = 1
    elif cc2_c == host_current:
        cc = 2
    else:
        cc = 0
    if debug: print('m', bin(cc1_c), bin(cc2_c), cc)
    return cc

host_current=0b10

def set_controls_source():
    # boot: 0b00100100
    ctrl0 = 0b00000000 # unmask all interrupts; don't autostart TX
    ctrl0 |= host_current << 2 # set host current advertisement pullups
    i2c.writeto_mem(FUSB302_I2C_SLAVE_ADDR, TCPC_REG_CONTROL0, bytes((ctrl0,)) )
    i2c.writeto_mem(0x22, 0x06, bytes((ctrl0,)) )
    # boot: 0b00000110
    ctrl3 = 0b00000110 # no automatic packet retries
    i2c.writeto_mem(FUSB302_I2C_SLAVE_ADDR, TCPC_REG_CONTROL3, bytes((ctrl3,)) )
    # boot: 0b00000010
    #ctrl2 = 0b00000000 # disable DRP toggle. setting it to Do Not Use o_o ???
    #i2c.writeto_mem(FUSB302_I2C_SLAVE_ADDR, TCPC_REG_CONTROL2, bytes((ctrl2,)) )

def set_wake(state):
    # boot: 0b00000010
    ctrl2 = i2c.readfrom_mem(0x22, 0x08, 1)[0]
    clear_mask = ~(1 << 3) & 0xFF
    ctrl2 &= clear_mask
    if state:
        ctrl2 | (1 << 3)
    i2c.writeto_mem(0x22, 0x08, bytes((ctrl2,)) )

def flush_receive():
    x = i2c.readfrom_mem(FUSB302_I2C_SLAVE_ADDR, TCPC_REG_CONTROL1, 1)[0]
    mask = 0b100 # flush receive
    x |= mask
    i2c.writeto_mem(FUSB302_I2C_SLAVE_ADDR, TCPC_REG_CONTROL1, bytes((x,)) )

def flush_transmit():
    x = i2c.readfrom_mem(FUSB302_I2C_SLAVE_ADDR, TCPC_REG_CONTROL0, 1)[0]
    mask = 0b01000000 # flush transmit
    x |= mask
    i2c.writeto_mem(FUSB302_I2C_SLAVE_ADDR, TCPC_REG_CONTROL0, bytes((x,)) )

def enable_tx(cc):
    # enables switch on either CC1 or CC2
    x = i2c.readfrom_mem(FUSB302_I2C_SLAVE_ADDR, TCPC_REG_SWITCHES1, 1)[0]
    x1 = x
    mask = 0b10 if cc == 2 else 0b1
    x &= 0b10011100 # clearing both TX bits and revision bits
    x |= mask
    x |= 0b100
    x |= 0b10 << 5 # revision 3.0
    #print('et', bin(x1), bin(x), cc)
    i2c.writeto_mem(FUSB302_I2C_SLAVE_ADDR, TCPC_REG_SWITCHES1, bytes((x,)) )

def set_roles(power_role = 1, data_role = 0):
    x = i2c.readfrom_mem(0x22, 0x03, 1)[0]
    x &= 0b01101111 # clearing both role bits
    x |= power_role << 7
    x |= data_role << 7
    i2c.writeto_mem(0x22, 0x03, bytes((x,)) )

def power():
    # enables all power circuits
    x = i2c.readfrom_mem(FUSB302_I2C_SLAVE_ADDR, TCPC_REG_POWER, 1)[0]
    mask = 0b1111
    x |= mask
    i2c.writeto_mem(FUSB302_I2C_SLAVE_ADDR, TCPC_REG_POWER, bytes((x,)) )

def polarity():
    # reads polarity and role bits from STATUS1A
    return (i2c.readfrom_mem(FUSB302_I2C_SLAVE_ADDR, TCPC_REG_STATUS1A, 1)[0] >> 3) & 0b111
    #'0b110001'

def interrupts():
    # return all interrupt registers
    return i2c.readfrom_mem(FUSB302_I2C_SLAVE_ADDR, TCPC_REG_INTERRUPTA, 2)+i2c.readfrom_mem(FUSB302_I2C_SLAVE_ADDR, TCPC_REG_INTERRUPT, 1)

# interrupts are cleared just by reading them, it seems
#def clear_interrupts():
#    # clear interrupt
#    i2c.writeto_mem(FUSB302_I2C_SLAVE_ADDR, TCPC_REG_INTERRUPTA, bytes([0]))
#    i2c.writeto_mem(FUSB302_I2C_SLAVE_ADDR, TCPC_REG_INTERRUPT, bytes([0]))

# this is a way better way to do things than the following function -
# the read loop should be ported to this function, and the next ome deleted
def rxb_state():
    # get read buffer interrupt states - (rx buffer empty, rx buffer full)
    st = i2c.readfrom_mem(FUSB302_I2C_SLAVE_ADDR, TCPC_REG_STATUS1, 1)[0]
    return ((st & 0b100000) >> 5, (st & 0b10000) >> 4)

# TODO: yeet
def rxb_state():
    st = i2c.readfrom_mem(FUSB302_I2C_SLAVE_ADDR, TCPC_REG_STATUS1, 1)[0]
    return ((st & 0b110000) >> 4, (st & 0b11000000) >> 6)

def get_rxb(l=80):
    # read from FIFO
    return i2c.readfrom_mem(FUSB302_I2C_SLAVE_ADDR, TCPC_REG_FIFOS, l)

def hard_reset():
    i2c.writeto_mem(FUSB302_I2C_SLAVE_ADDR, TCPC_REG_CONTROL3, bytes([0b1000000]))
    return i2c.readfrom_mem(FUSB302_I2C_SLAVE_ADDR, TCPC_REG_CONTROL3, 1)

def find_cc(fn=measure_source, debug=False):
    cc = fn(debug=debug)
    flush_receive()
    enable_tx(cc)
    read_cc(cc)
    flush_transmit()
    flush_receive()
    #import gc; gc.collect()
    reset_pd()
    return cc

# FUSB toggle logic shorthands
# currently unused

polarity_values = (
  (0, 0),   # 000: logic still running
  (1, 0),   # 001: cc1, src
  (2, 0),   # 010: cc2, src
  (-1, -1), # 011: unknown
  (-1, -1), # 100: unknown
  (1, 1),   # 101: cc1, snk
  (2, 1),   # 110: cc2, snk
  (0, 2),   # 111: audio accessory
)

current_values = (
    "Ra/low",
    "Rd-Default",
    "Rd-1.5",
    "Rd-3.0"
)

def p_pol():
    return polarity_values[polarity()]

def p_int(a=None):
    if a is None:
        a = interrupts()
    return [bin(x) for x in a]

def p_cur():
    return current_values[cc_current()]

########################
#
# USB-C stacc code
#
########################

pdo_requested = False
pdos = []
timing_start = 0
timing_end = 0

# set to -1 because it's incremented before each command is sent out
msg_id = -1

def increment_msg_id():
    global msg_id
    msg_id += 1
    if msg_id == 8: msg_id = 0
    return msg_id

def reset_msg_id():
    global msg_id
    msg_id = -1

sent_messages = []

def source_flow():
  global psu_advertisement, advertisement_counter, sent_messages
  psu_advertisement = create_pdo('fixed', 5000, 1500, 0, 8) #maybe try 2100mA
  counter = 0
  reset_msg_id()
  sleep(0.3)
  print("sending advertisement")
  send_advertisement(psu_advertisement)
  advertisement_counter = 1
  profile_selected = False
  try:
   timeout = 0.00001
   while True:
    if rxb_state()[0] == 0: # buffer non-empty
        d = get_message()
        msg_types = control_message_types if d["c"] else data_message_types
        msg_name = msg_types[d["t"]]
        # now we do things depending on the message type that we received
        if msg_name == "GoodCRC": # example
            print("GoodCRC")
        elif msg_name == "Request":
            profile_selected = True
            process_psu_request(psu_advertisement, d)
        """elif msg_name == "Vendor_Defined":
            parse_vdm(d)
            react_vdm(d)"""
        show_msg(d)
    for message in sent_messages:
        sys.stdout.write('> ')
        sys.stdout.write(myhex(message))
        sys.stdout.write('\n')
    sent_messages = []
    sleep(timeout) # so that ctrlc works
    counter += 1
    if counter == 10000:
        counter = 0
        if not profile_selected and advertisement_counter < 30:
            print("sending advertisement")
            send_advertisement(psu_advertisement)
            advertisement_counter += 1
    if int_g() == 0:
        i = interrupts()
        print(i)
        i_reg = i[2]
        if i_reg & 0x80: # I_VBUSOK
            print("I_VBUSOK")
            #pass # just a side effect of vbus being attached
        if i_reg & 0x40: # I_ACTIVITY
            print("I_ACTIVITY")
            pass # just a side effect of CC comms I think?
        if i_reg & 0x20: # I_COMP_CHNG
            print("I_COMP_CHNG")
            # this is where detach can occur, let's check
            cc = find_cc(fn=measure_source)
            if cc == 0:
                print("Disconnect detected!")
                return # we exiting this
        if i_reg & 0x10: # I_CRC_CHK
            pass # new CRC, just a side effect of CC comms
        if i_reg & 0x8: # I_ALERT
            print("I_ALERT")
            x = i2c.readfrom_mem(0x22, 0x41, 1)[0]
            print(bin(x))
        if i_reg & 0x4: # I_WAKE
            print("I_WAKE")
        if i_reg & 0x2: # I_COLLISION
            print("I_COLLISION")
        if i_reg & 0x1: # I_BC_LVL
            print("I_BC_LVL")
  except KeyboardInterrupt:
    print("CtrlC")
    raise

########################
#
# Packet reception
# and parsing code
#
########################

control_message_types = [
    "Reserved",
    "GoodCRC",
    "GotoMin",
    "Accept",
    "Reject",
    "Ping",
    "PS_RDY",
    "Get_Source_Cap",
    "Get_Sink_Cap",
    "DR_Swap",
    "PR_Swap",
    "VCONN_Swap",
    "Wait",
    "Soft_Reset",
    "Data_Reset",
    "Data_Reset_Complete",
    "Not_Supported",
    "Get_Source_Cap_Extended",
    "Get_Status",
    "FR_Swap",
    "Get_PPS_Status",
    "Get_Country_Codes",
    "Get_Sink_Cap_Extended",
    "Get_Source_Info",
    "Get_Revision",
]

data_message_types = [
    "Reserved",
    "Source_Capabilities",
    "Request",
    "BIST",
    "Sink_Capabilities",
    "Battery_Status",
    "Alert",
    "Get_Country_Info",
    "Enter_USB",
    "EPR_Request",
    "EPR_Mode",
    "Source_Info",
    "Revision",
    "Reserved",
    "Reserved",
    "Vendor_Defined",
]

header_starts = [0xe0, 0xc0]

def get_message(get_rxb=get_rxb):
    header = 0
    d = {}
    # we might have to get through some message data!
    while header not in header_starts:
        header = get_rxb(1)[0]
        if header == 0:
            return
        if header not in header_starts:
            # this will be printed, eventually.
            # the aim is that it doesn't delay code in the way that print() seems to
            sys.stdout.write("disc {}\n".format(hex(header)))
    d["o"] = False # incoming message
    d["h"] = header
    b1, b0 = get_rxb(2)
    d["b0"] = b0
    d["b1"] = b1
    sop = 1 if header == 0xe0 else 0
    d["st"] = sop
    # parsing the packet header
    prole = b0 & 1
    d["pr"] = prole
    drole = b1 >> 5 & 1
    d["dr"] = drole
    msg_type = b1 & 0b11111
    pdo_count = (b0 >> 4) & 0b111
    d["dc"] = pdo_count
    d["t"] = msg_type
    d["c"] = pdo_count == 0 # control if True else data
    msg_index = int((b0 >> 1) & 0b111)
    d["i"] = msg_index
    if pdo_count:
        read_len = pdo_count*4
        pdos = get_rxb(read_len)
        d["d"] = pdos
    _ = get_rxb(4) # crc
    rev = b1 >> 6
    d["r"] = rev
    is_ext = b0 >> 7 # extended
    d["e"] = is_ext
    msg_types = control_message_types if pdo_count == 0 else data_message_types
    msg_name = msg_types[d["t"]]
    d["tn"] = msg_name
    if msg_name == "Vendor_Defined":
        parse_vdm(d)
    return d

def show_msg(d):
    ## d["h"] = header
    ## sop = 1 if header == 0xe0 else 0
    ## d["st"] = sop
    sop_str = "" if d["st"] else "'"
    # parsing the packet header
    ## d["pr"] = prole
    prole_str = "NC"[d["pr"]] if d["st"] else "R"
    drole_str = "UD"[d["dr"]] if d["st"] else "R"
    ## d["dc"] = pdo_count
    ## d["t"] = msg_type
    ## d["c"] = pdo_count == 0 # control if True else data
    message_types = control_message_types if d["c"]  else data_message_types
    ## d["i"] = msg_index
    msg_type_str = message_types[d["t"]] if d["t"] < len(message_types) else "Reserved"
    ## if pdo_count:
    ##    d["d"] = pdos
    ## d["r"] = rev
    rev_str = "123"[d["r"]]
    ## d["e"] = is_ext
    ext_str = ["std", "ext"][d["e"]]
    # msg direction
    dir_str = ">" if d["o"] else "<"
    if d["dc"]:
        # converting "41 80 00 FF A4 25 00 2C" to "FF008041 2C0025A4"
        pdo_strs = []
        pdo_data = myhex(d["d"]).split(' ')
        for i in range(len(pdo_data)//4):
           pdo_strs.append(''.join(reversed(pdo_data[(i*4):][:4])))
        pdo_str = " ".join(pdo_strs)
    else:
        pdo_str = ""
    sys.stdout.write("{} {}{}: {}; p{} d{} r{}, {}, p{}, {} {}\n".format(dir_str, d["i"], sop_str, msg_type_str, prole_str, drole_str, rev_str, ext_str, d["dc"], myhex((d["b0"], d["b1"])).replace(' ', ''), pdo_str))
    # extra parsing where possible
    if msg_type_str == "Vendor_Defined":
        print_vdm(d)
        #sys.stdout.write(str(d["d"]))
        #sys.stdout.write('\n')
    elif msg_type_str == "Source_Capabilities":
        sys.stdout.write(str(get_pdos(d)))
        sys.stdout.write('\n')
    return d

########################
#
# PDO parsing code
#
########################

pdo_types = ['fixed', 'batt', 'var', 'pps']
pps_types = ['spr', 'epr', 'res', 'res']

def parse_pdo(pdo):
    pdo_t = pdo_types[pdo[3] >> 6]
    if pdo_t == 'fixed':
        current_h = pdo[1] & 0b11
        current_b = ( current_h << 8 ) | pdo[0]
        current = current_b * 10
        voltage_h = pdo[2] & 0b1111
        voltage_b = ( voltage_h << 6 ) | (pdo[1] >> 2)
        voltage = voltage_b * 50
        peak_current = (pdo[2] >> 4) & 0b11
        return (pdo_t, voltage, current, peak_current, pdo[3])
    elif pdo_t == 'batt':
        # TODO
        return ('batt', pdo)
    elif pdo_t == 'var':
        current_h = pdo[1] & 0b11
        current = ( current_h << 8 ) | pdo[0]*10
        # TODO
        return ('var', current, pdo)
    elif pdo_t == 'pps':
        t = (pdo[3] >> 4) & 0b11
        limited = (pdo[3] >> 5) & 0b1
        max_voltage_h = pdo[3] & 0b1
        max_voltage_b = (max_voltage_h << 7) | pdo[2] >> 1
        max_voltage = max_voltage_b * 100
        min_voltage = pdo[1] * 100
        max_current_b = pdo[0] & 0b1111111
        max_current = max_current_b * 50
        return ('pps', pps_types[t], max_voltage, min_voltage, max_current, limited)

def create_pdo(pdo_t, *args):
    print(pdo_t, *args)
    assert(pdo_t in pdo_types)
    pdo = [0 for i in range(4)]
    if pdo_t == 'fixed':
        voltage, current, peak_current, pdo3 = args
        current_v = current // 10
        current_h = (current_v >> 8) & 0b11
        current_l = current_v & 0xFF
        pdo[1] = current_h
        pdo[0] = current_l
        """
        current_h = pdo[1] & 0b11
        current_b = ( current_h << 8 ) | pdo[0]
        current = current_b * 10
        """
        voltage_v = voltage // 50
        pdo[2] = (voltage_v >> 6) & 0b1111
        pdo[1] |= (voltage_v & 0b111111) << 2
        """
        voltage_h = pdo[2] & 0b1111
        voltage_b = ( voltage_h << 6 ) | (pdo[1] >> 2)
        voltage = voltage_b * 50
        """
        pdo[2] |= (peak_current & 0b11) << 4
        peak_current = (pdo[2] >> 4) & 0b11
        pdo[3] = pdo3
        pdo[3] |= pdo_types.index(pdo_t) << 6
    elif pdo_t == 'batt':
        raise Exception("Batt PDO formation not implemented yet!")
    elif pdo_t == 'var':
        raise Exception("Variable PDO formation not implemented yet!")
    elif pdo_t == 'pps':
        """t = (pdo[3] >> 4) & 0b11
        limited = (pdo[3] >> 5) & 0b1
        max_voltage_h = pdo[3] & 0b1
        max_voltage_b = (max_voltage_h << 7) | pdo[2] >> 1
        max_voltage = max_voltage_b * 100
        min_voltage = pdo[1] * 100
        max_current_b = pdo[0] & 0b1111111
        max_current = max_current_b * 50
        return ('pps', pps_types[t], max_voltage, min_voltage, max_current, limited)"""
        raise Exception("PPS PDO formation not implemented yet!")
    print(parse_pdo(bytes(pdo)))
    return pdo

def get_pdos(d):
    pdo_list = []
    pdos = d["d"]
    for pdo_i in range(d["dc"]):
        pdo_bytes = pdos[(pdo_i*4):][:4]
        #print(myhex(pdo_bytes))
        parsed_pdo = parse_pdo(pdo_bytes)
        pdo_list.append(parsed_pdo)
    return pdo_list

########################
#
# Command sending code
# and simple commands
#
########################

def send_command(command, data, msg_id=None, rev=0b10, power_role=1, data_role=0):
    msg_id = increment_msg_id() if msg_id is None else msg_id
    sop_seq = [0x12, 0x12, 0x12, 0x13, 0x80]
    eop_seq = [0xff, 0x14, 0xfe, 0xa1]
    obj_count = len(data) // 4

    header = [0, 0] # hoot hoot !

    header[0] |= rev << 6 # PD revision
    header[0] |= (data_role & 0b1) << 5 # PD revision
    header[0] |= (command & 0b11111)

    header[1] = power_role & 0b1
    header[1] |= (msg_id & 0b111) << 1 # message ID
    header[1] |= obj_count << 4

    message = header+data

    sop_seq[4] |= len(message)

    i2c.writeto_mem(FUSB302_I2C_SLAVE_ADDR, TCPC_REG_FIFOS, bytes(sop_seq) )
    i2c.writeto_mem(FUSB302_I2C_SLAVE_ADDR, TCPC_REG_FIFOS, bytes(message) )
    i2c.writeto_mem(FUSB302_I2C_SLAVE_ADDR, TCPC_REG_FIFOS, bytes(eop_seq) )

    sent_messages.append(message)

def soft_reset():
    send_command(0b01101, [])
    reset_msg_id()

########################
#
# PSU request processing code
#
########################

def send_advertisement(psu_advertisement):
    #data = [bytes(a) for a in psu_advertisement]
    data = psu_advertisement
    send_command(0b1, data, power_role=1, data_role=0)

def process_psu_request(psu_advertisement, d):
    print(d)
    profile = ((d["d"][3] >> 4)&0b111)-1
    print("Selected profile", profile)
    if profile not in range(len(psu_advertisement)):
        set_power_rail('off')
    else:
        send_command(0b11, [], power_role=1, data_role=0) # Accept
        sleep(0.1)
        if profile == 0:
            set_power_rail('5V')
        send_command(0b110, [], power_role=1, data_role=0) # PS_RDY

########################
#
# VDM parsing and response code
#
########################

vdm_commands = [
    "Reserved",
    "Discover Identity",
    "Discover SVIDs",
    "Discover Modes",
    "Enter Mode",
    "Exit Mode",
    "Attention"]

svids = {
    0xff00: 'SID',
    0xff01: 'DisplayPort',
}

dp_commands = {
    0x10: "DP Status Update",
    0x11: "DP Configure"}

vdm_cmd_types = ["REQ", "ACK", "NAK", "BUSY"]

# reply-with-hardcoded code
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

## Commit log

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2023-12-17 some more caps n stuff
    [the_extender.kicad_sch]
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2023-12-21 did things, tried to arrange components
    [the_extender.kicad_pcb, the_extender.kicad_sch]
2023-12-21 trying to layout board
    [the_extender.kicad_pcb, the_extender.kicad_sch]
2023-12-22 got most stuff stuffed onto the PCB
    [the_extender.kicad_pcb, the_extender.kicad_sch]
2023-12-22 flip layers so power is routed on heavier traces
    [the_extender.kicad_pcb]
2023-12-22 done some more stuff
    [the_extender.kicad_pcb]
2023-12-23 i might have finished routing signals
    [the_extender.kicad_pcb, the_extender.kicad_sch]
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2023-12-23 added some missing connections
    [the_extender.kicad_pcb, the_extender.kicad_sch]
2023-12-23 fix bugs
    [the_extender.kicad_pcb, the_extender.kicad_sch]
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2023-12-23 add missing trace, fix bugs
    [the_extender.kicad_pcb, the_extender.kicad_sch]
2023-12-25 added even more connections i forgot
    [the_extender.kicad_pcb, the_extender.kicad_sch]
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2023-12-25 better groundplane for pb chip
    [the_extender.kicad_pcb]
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2023-12-27 reread IP5310 datasheet, better groundplanes, other
    [the_extender.kicad_pcb, the_extender.kicad_sch]
2023-12-27 actually fix U6 footprint
    [the_extender.kicad_pcb]
2023-12-28 fix clearances
    [the_extender.kicad_pcb]
2023-12-28 more clearance and ground stuff
    [the_extender.kicad_pcb]
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2023-12-28 dont need VBUS on FUSB302
    that just kills them sometimes
    [the_extender.kicad_pcb, the_extender.kicad_sch]
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2023-12-28 update to kicad 7
    [the_extender.kicad_pcb, the_extender.kicad_sch]
2023-12-28 stuff
    clearances, remove unnesaccary components, etc
    [the_extender.kicad_pcb, the_extender.kicad_sch]
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2023-12-28 switch to new connector, part a
    [the_extender.kicad_pcb]
2023-12-28 new connector, part 2
    [the_extender.kicad_pcb, the_extender.kicad_sch]
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2023-12-29 added CC test pads
    [the_extender.kicad_pcb, the_extender.kicad_sch]
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2023-12-31 take out more sink stuff
    this is nice code, but the extender should never be a sink and i want to keep this as short as possible. sorry
    [main.py]
2024-01-01 added USB C flat-flex cable adapters
    [usb_c_ffc.kicad_pcb, usb_c_ffc.kicad_sch]
2024-01-02 giving up on eeprom emulation, not enough board space
    [the_extender.kicad_pcb, the_extender.kicad_sch]
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2024-01-04 applied changes to PCB
    [the_extender.kicad_pcb, the_extender.kicad_sch]
2024-01-04 add EEPROM emulation back
    [the_extender.kicad_pcb, the_extender.kicad_sch]
2024-01-04 silkscreen overlap, geo reannotate, teardrops
    [the_extender.kicad_pcb, the_extender.kicad_sch]
2024-01-04 oops, forgot to refill zones
    [the_extender.kicad_pcb]
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2024-01-04 protect RP2040 from 3V6
    [the_extender.kicad_pcb, the_extender.kicad_sch]
2024-01-05 switching to IP5306, step 1: schematic
    [the_extender.kicad_sch]
2024-01-05 oh yeah, the 5k1 resistors
    [the_extender.kicad_sch]
2024-01-05 switching to IP5306, step 2: PCB
    [the_extender.kicad_pcb, the_extender.kicad_sch]
2024-01-05 had to move the IC a little
    [the_extender.kicad_pcb, the_extender.kicad_sch]
2024-01-05 fixup silkscreen, voltage limits, etc
    [the_extender.kicad_pcb, the_extender.kicad_sch]
2024-01-05 fix U6 being detected as "additional footprint"
    [the_extender.kicad_pcb, the_extender.kicad_sch]
2024-01-07 fix me fucking up footprints
    [the_extender.kicad_pcb, the_extender.kicad_sch]
2024-01-07 use mousebites on cable instead
    [usb_c_ffc.kicad_pcb]
2024-01-07 ah whatever
    i will just go with 3 seperate PCBs. its actually cheaper that way
    [usb_c_ffc.kicad_pcb]
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2024-01-10 still not quite done
    [the_extender.kicad_pcb]
2024-01-11 reconnect VBUS to FUSB302
    i think its needed for the pullups
    [the_extender.kicad_pcb, the_extender.kicad_sch]
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2024-01-11 switch 3v3 footprint, fixup stuff
    [the_extender.kicad_pcb, the_extender.kicad_sch]
2024-01-13 trying to do a customizable case in scad
    [extender_base.scad, full_phone_case.scad, stitch_on_case.scad]
2024-01-17 switch to cheaper and smaller usb hub, part 1
    [the_extender.kicad_sch]
2024-01-17 switch usb hub, part 2: PCB
    [the_extender.kicad_pcb, the_extender.kicad_sch]
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2024-01-17 small fixes
    [the_extender.kicad_pcb, the_extender.kicad_sch]
2024-01-17 Switch to linear LDO Regulator to decrease cost
    might also improve ADC accuracy...
    [the_extender.kicad_pcb, the_extender.kicad_sch]
2024-01-17 slightly improved thermal fill
    [the_extender.kicad_pcb]
2024-01-17 removed back s.mask from some in-pad vias
    [the_extender.kicad_pcb]
2024-01-17 oh, this belongs to an earlier commit
    [the_extender.kicad_sch]
2024-01-18 update LCSC parts
    i always forgot to update the schematic :facepalm:
    [the_extender.kicad_pcb, the_extender.kicad_sch]
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2024-01-18 fix lcsc parts
    [the_extender.kicad_pcb, the_extender.kicad_sch]
2024-01-18 fix bom excludes
    [the_extender.kicad_pcb, the_extender.kicad_sch]
2024-01-18 change inductor and fix things
    [the_extender.kicad_pcb, the_extender.kicad_sch]
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2024-01-21 fix some more in-pad-vias
    [the_extender.kicad_pcb]
2024-01-26 space comonents out more in audio section
    [the_extender.kicad_pcb]
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2024-01-26 forgot to refill zones. oops
    [the_extender.kicad_pcb]
2024-01-26 fix testpad labels
    [the_extender.kicad_pcb]
2024-01-26 fix LCSC part numbers
    [the_extender.kicad_pcb, the_extender.kicad_sch]
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2024-02-09 added headphone plug-in detection, other stuff
    [the_extender.kicad_pcb, the_extender.kicad_sch]
2024-02-09 fix USB3 footprint
    [the_extender.kicad_pcb]
2024-02-09 silkscreen slightly more readable
    [the_extender.kicad_pcb]
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2024-02-15 ok, just a regular diode then...
    [the_extender.kicad_pcb, the_extender.kicad_sch]
2024-02-15 fix DRC errors
    [the_extender.kicad_pcb, the_extender.kicad_sch]
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2024-02-15 switche diode FP, shuffle silk around
    [the_extender.kicad_pcb, the_extender.kicad_sch]
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2024-02-16 move USB3 cable to seperate folder
    [usb_c_ffc.kicad_pcb, usb_c_ffc.kicad_sch, usb_c_ffc_bot.kicad_pcb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]
2024-02-16 added nice little USB2 cable variant
    [usb_c_2.kicad_pcb, usb_c_2.kicad_sch]
2024-02-16 hide too small silkscreen text
    [usb_c_2.kicad_pcb]
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2024-02-17 switching back to IP5310, step 1: schematic
    Switching back to IP5310 with different 5V enable circuit
    This has several advantages:
    * being able to output power via the charging port
    * being sure the 5V power will be able to be switched off
    * 3A-capable supply
    Disadvantage:
    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
    [the_extender.kicad_sch]
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2024-02-17 add way to measure VBUS
    [the_extender.kicad_pcb, the_extender.kicad_sch]
2024-02-17 silk slightly less horrible
    [the_extender.kicad_pcb]
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2024-02-18 add Li-Ion protection circuit
    [the_extender.kicad_pcb, the_extender.kicad_sch]
2024-02-18 cell protection fixes
    [the_extender.kicad_pcb, the_extender.kicad_sch]
2024-02-18 reinforce BATT- with solder, small fixes
    [the_extender.kicad_pcb]
2024-02-18 change RGB LED
    old one was out of stock
    [the_extender.kicad_pcb, the_extender.kicad_sch]
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2024-02-22 improved thermal areas, trace routing, other
    [the_extender.kicad_pcb]
2024-02-22 gnd fix
    [the_extender.kicad_pcb]
2024-02-22 auto clean and fix teardrops
    [the_extender.kicad_pcb]
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2024-02-22 why did the LCSC part numbers not transfer?
    [the_extender.kicad_pcb]
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2024-03-01 fix DRC error
    [the_extender.kicad_pcb]
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2024-03-01 Revert "Merge branch 'main' of https://github.com/H3wastooshort/the_extender"
    This reverts commit db196a6756d0956c3d1d8ec495d7e3985efbbc7b, reversing
    changes made to 4fcd2dbd9a370267836c4c164a7f38c8495f449e.
    [the_extender.kicad_pcb, the_extender.kicad_sch]
2024-03-01 Revert "stuff"
    This reverts commit 4fcd2dbd9a370267836c4c164a7f38c8495f449e.
    [the_extender.kicad_pcb]
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2024-03-17 correct revision
    [the_extender.kicad_sch]
2024-05-05 fix DRC complaint
    [the_extender.kicad_sch]
2024-05-23 try fixing GHA-rendered images
    [the_extender.kicad_pcb]
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2024-05-23 Revert "another attempt"
    This reverts commit 288c0018775d544f383a750716c72db4144e6e0d.
    [the_extender.kicad_pcb]
